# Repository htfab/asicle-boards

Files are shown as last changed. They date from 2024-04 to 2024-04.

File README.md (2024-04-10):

# Asicle boards

Contains two PCB designs for the Wordle clone on ASIC, [Asicle](https://github.com/htfab/asicle).

Asicle DIY uses only discrete transistors and passives for the supporting circuitry, with through-hole components for everything except the ASIC.

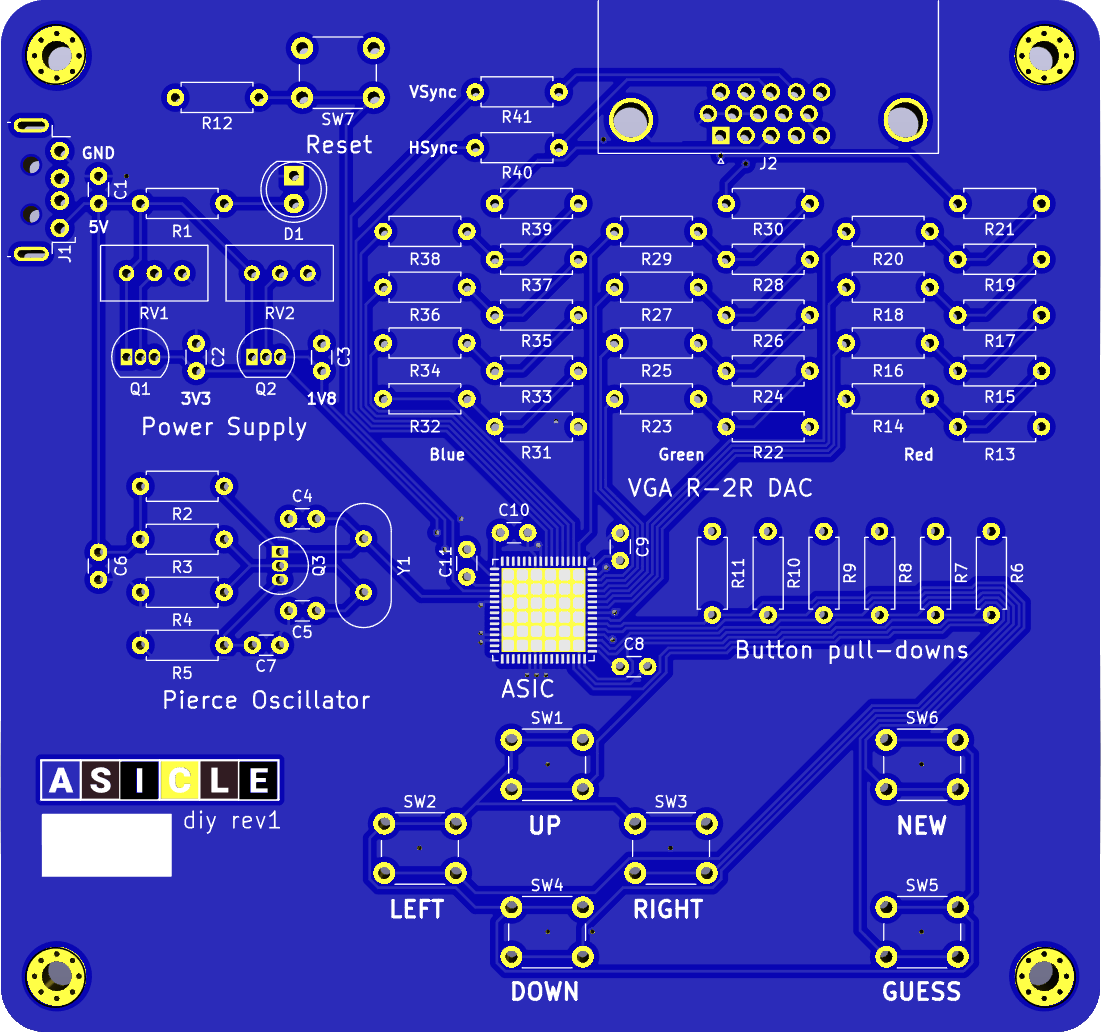
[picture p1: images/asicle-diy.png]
Asicle DIY front render


Asicle PRO uses standard commercial chips for voltage regulation, clock generation and VGA buffering for better reliability, and is designed with surface-mount components.

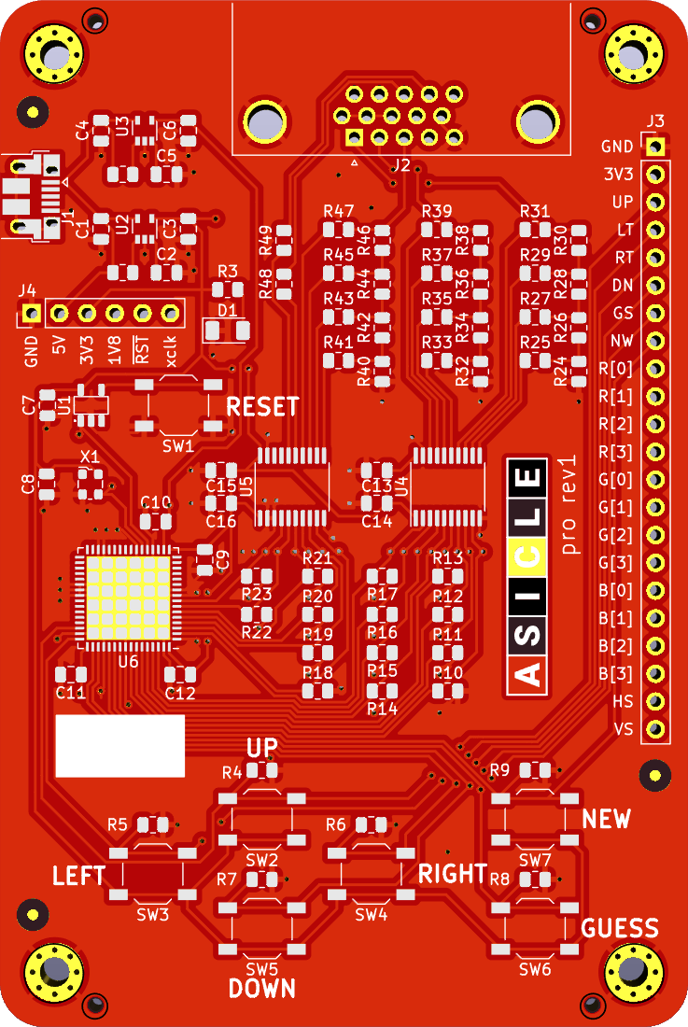
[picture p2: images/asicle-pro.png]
Asicle PRO front render


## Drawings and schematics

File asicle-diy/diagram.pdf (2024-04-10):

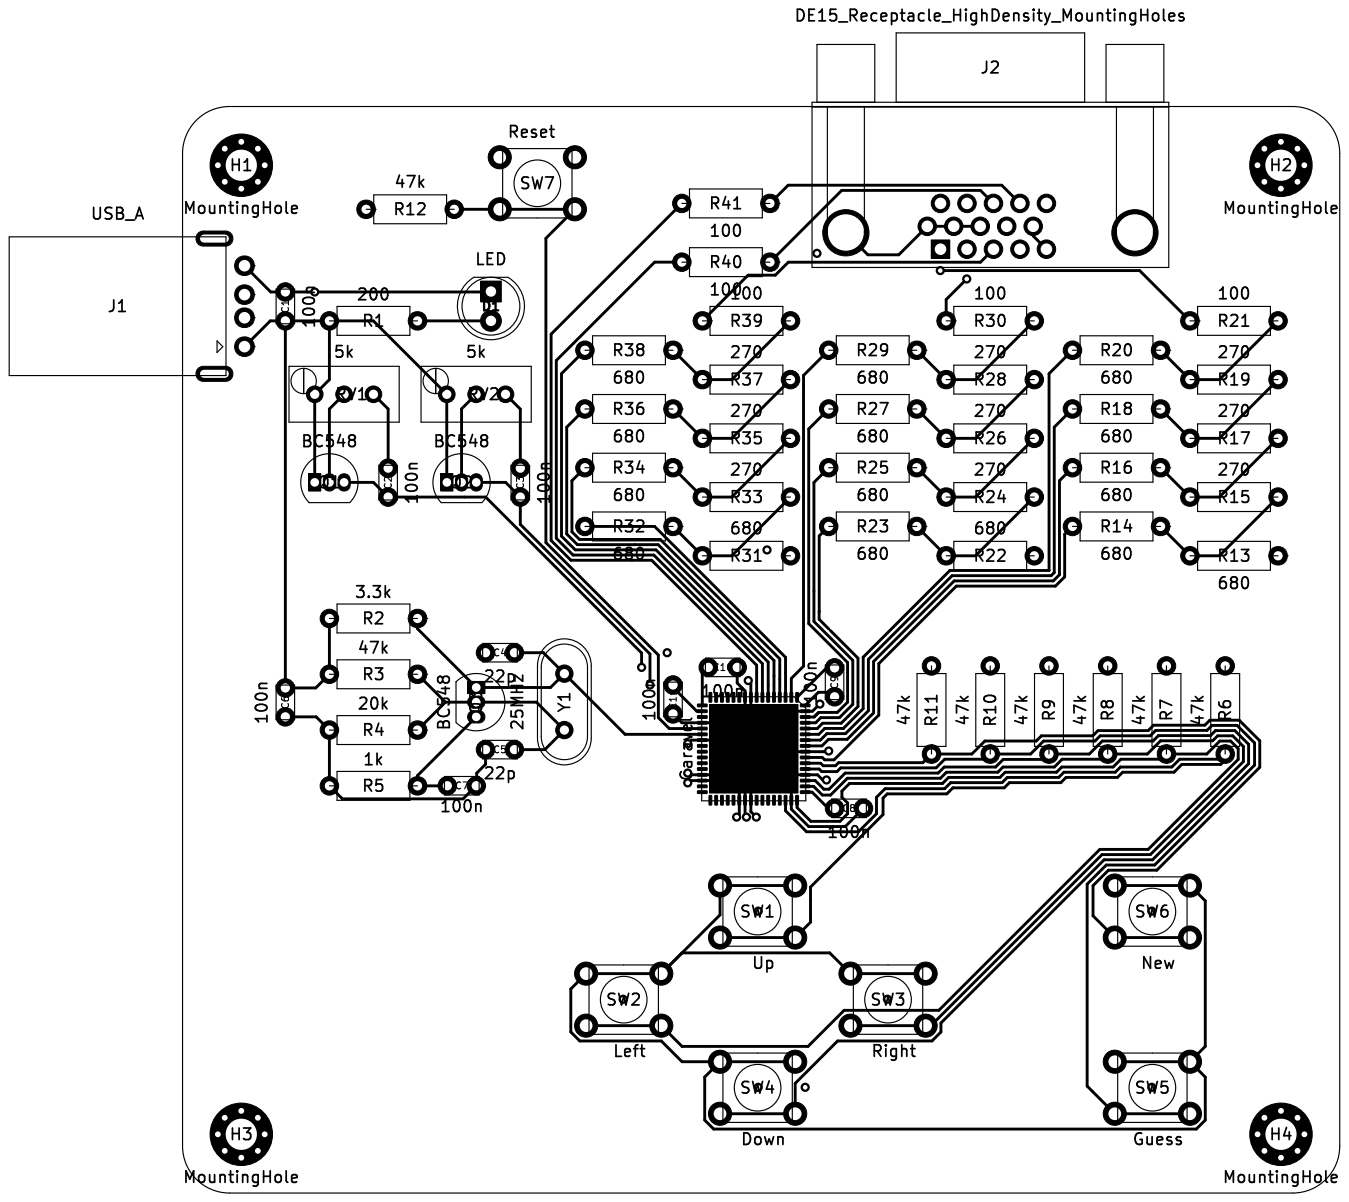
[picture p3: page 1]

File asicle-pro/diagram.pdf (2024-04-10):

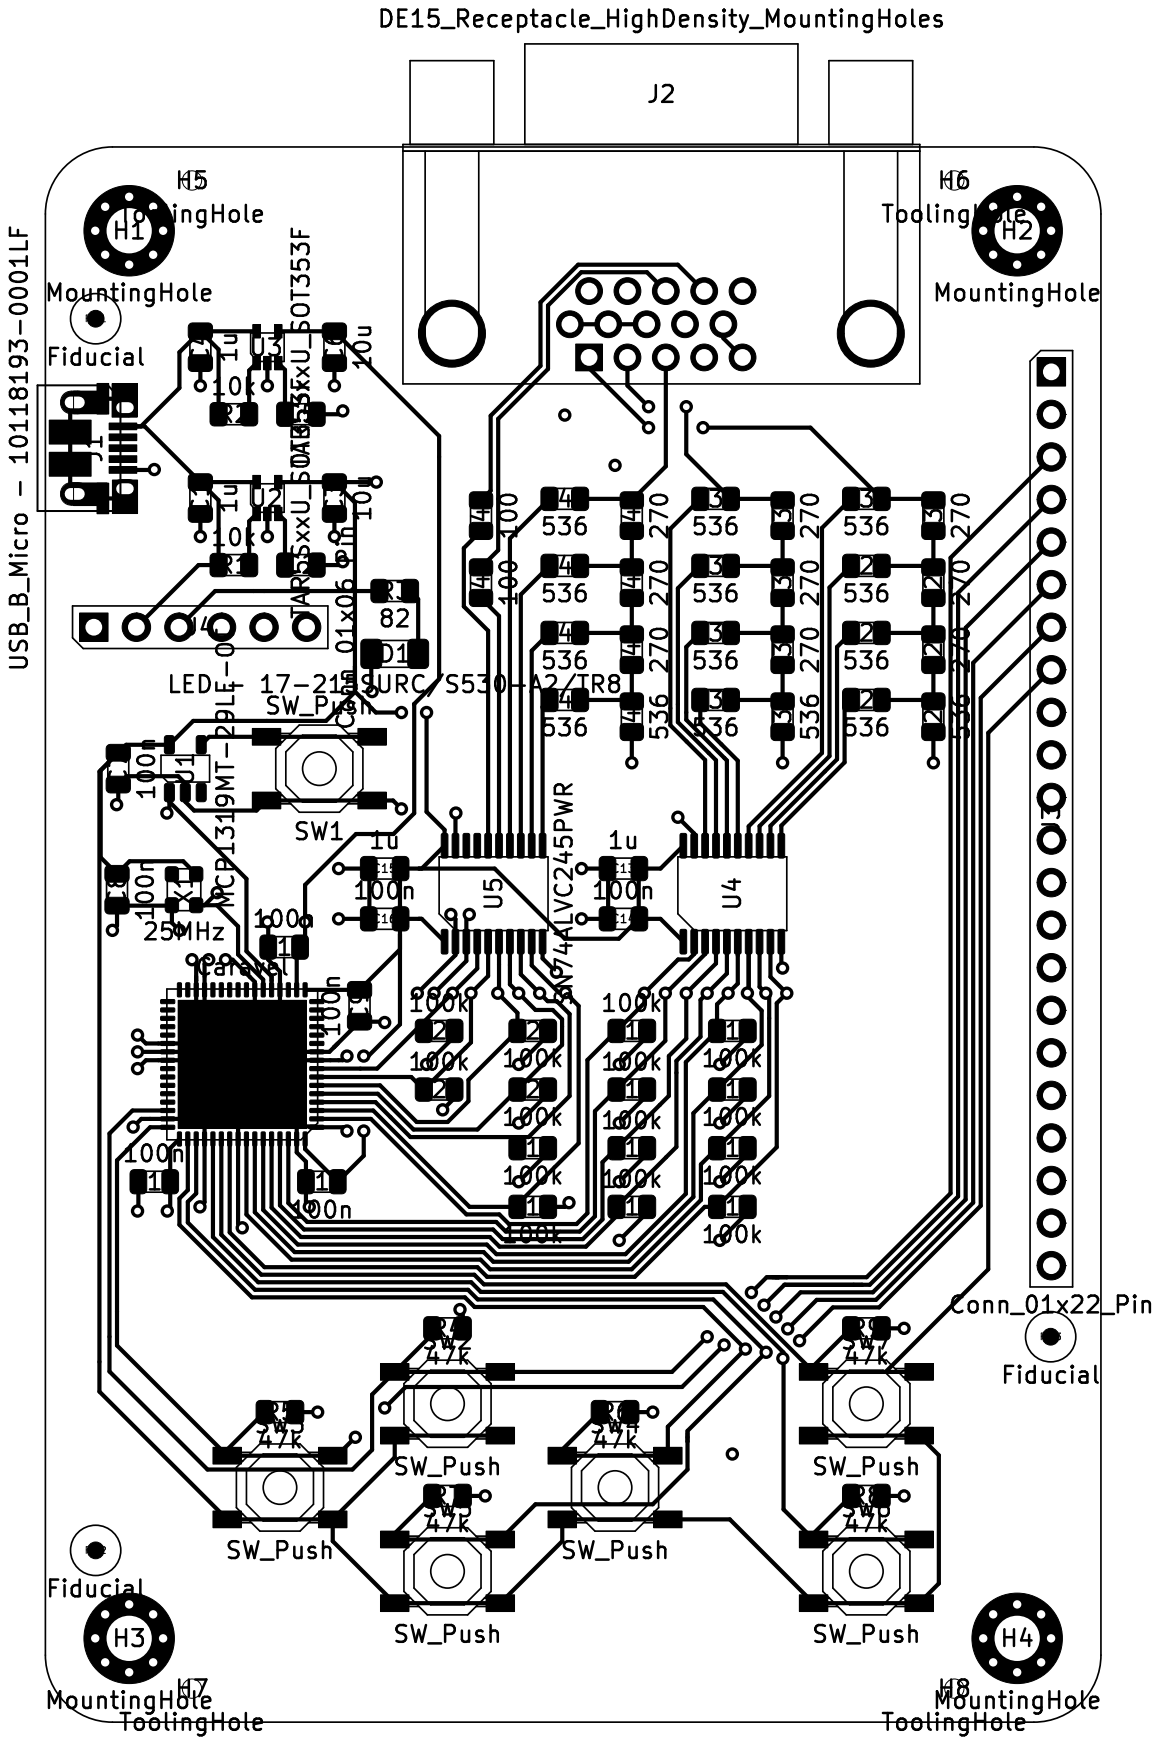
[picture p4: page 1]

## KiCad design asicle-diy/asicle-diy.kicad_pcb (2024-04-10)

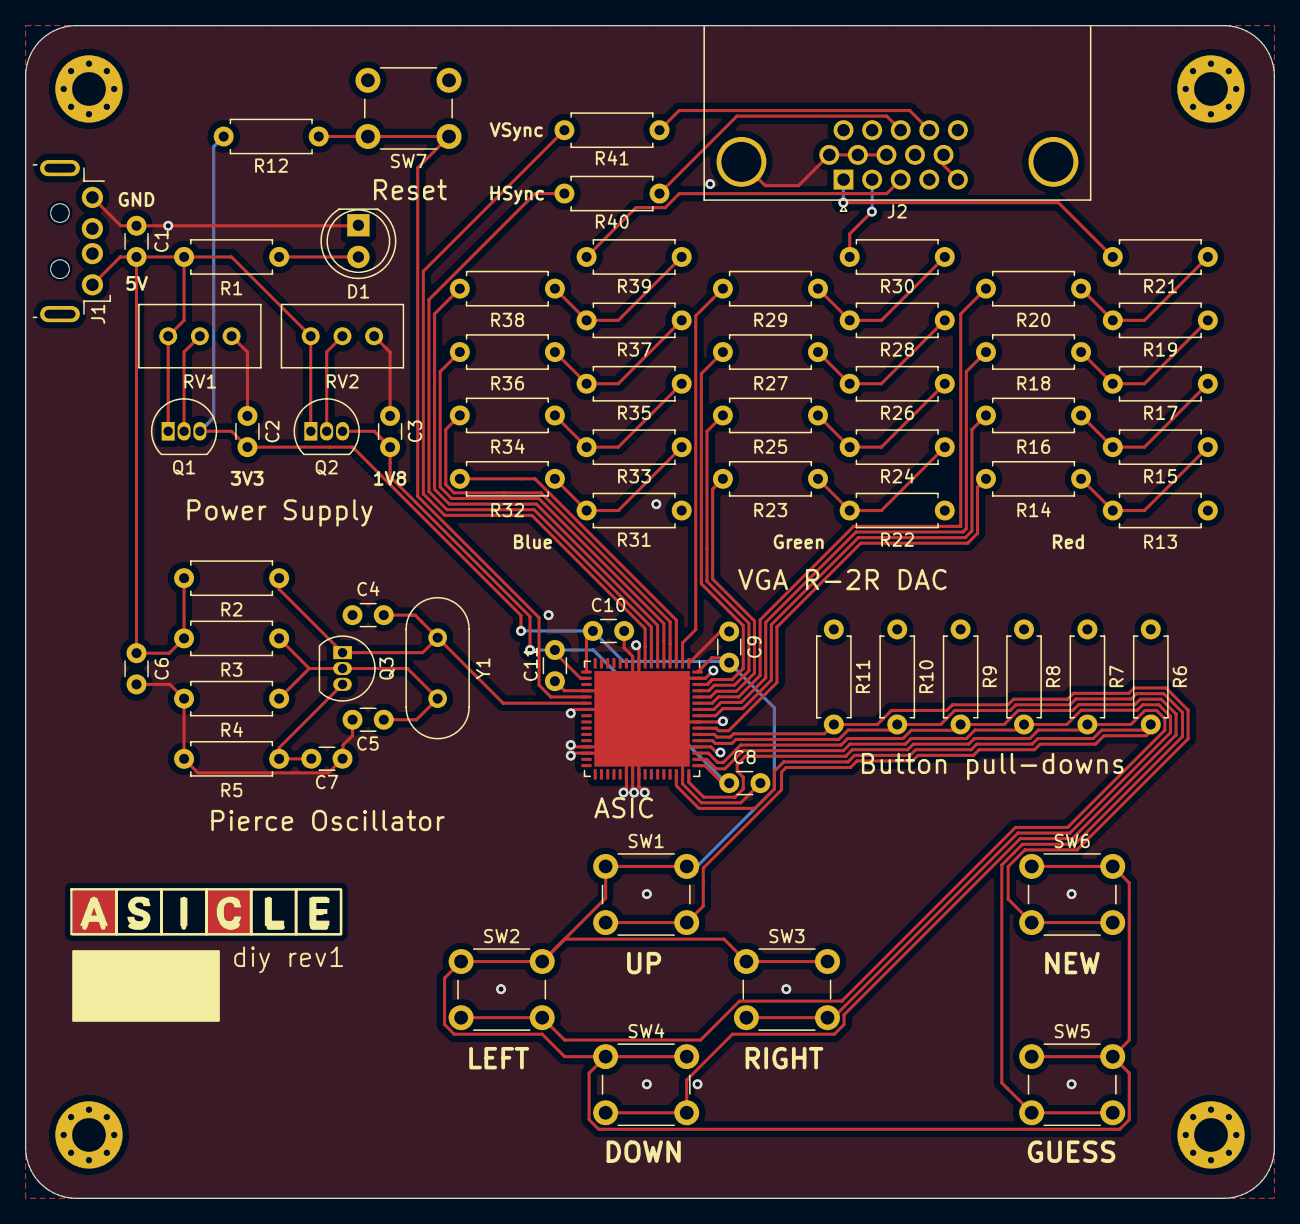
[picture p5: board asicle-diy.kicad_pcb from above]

Board: 2 copper layers, 100.1 x 94.0 mm, 73 parts (0 on the bottom side), 48 nets.

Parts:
C1, C2, C3, C6, C7, C8, C9, C10, C11: 100n; C_Disc_D3.0mm_W1.6mm_P2.50mm
C4, C5: 22p; C_Disc_D3.0mm_W1.6mm_P2.50mm
D1: LED; LED_D5.0mm
H1, H2, H3, H4: MountingHole; MountingHole_2.7mm_M2.5_Pad_Via
J1: USB_A; USB_A_LC_THT
J2: DE15_Receptacle_HighDensity_MountingHoles; DSUB-15-HD_Female_Horizontal_P2.29x1.98mm_EdgePinOffset8.35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
Q1, Q2, Q3: BC548; TO-92_Inline
R1: 200; R_Axial_DIN0207_L6.3mm_D2.5mm_P7.62mm_Horizontal
R2: 3.3k; R_Axial_DIN0207_L6.3mm_D2.5mm_P7.62mm_Horizontal
R3, R6, R7, R8, R9, R10, R11, R12: 47k; R_Axial_DIN0207_L6.3mm_D2.5mm_P7.62mm_Horizontal
R4: 20k; R_Axial_DIN0207_L6.3mm_D2.5mm_P7.62mm_Horizontal
R5: 1k; R_Axial_DIN0207_L6.3mm_D2.5mm_P7.62mm_Horizontal
R13, R14, R16, R18, R20, R22, R23, R25, R27, R29, R31, R32, R34, R36, R38: 680; R_Axial_DIN0207_L6.3mm_D2.5mm_P7.62mm_Horizontal
R15, R17, R19, R24, R26, R28, R33, R35, R37: 270; R_Axial_DIN0207_L6.3mm_D2.5mm_P7.62mm_Horizontal
R21, R30, R39, R40, R41: 100; R_Axial_DIN0207_L6.3mm_D2.5mm_P7.62mm_Horizontal
RV1, RV2: 5k; Potentiometer_Bourns_3296W_Vertical
SW1: Up; SW_PUSH_6mm
SW2: Left; SW_PUSH_6mm
SW3: Right; SW_PUSH_6mm
SW4: Down; SW_PUSH_6mm
SW5: Guess; SW_PUSH_6mm
SW6: New; SW_PUSH_6mm
SW7: Reset; SW_PUSH_6mm
U3: Caravel; QFN-64-1EP_9x9mm_P0.5mm_EP7.65x7.65mm
Y1: 25MHz; Crystal_HC49-U_Vertical

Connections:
+1V8: C3.1, C8.1, C11.1, Q2.3 (E), U3.18 (vccd), U3.49 (vccd1)
+3V3: C2.1, C9.2, C10.1, Q1.3 (E), R12.2, SW1.1, SW2.1, SW3.1, SW4.1, SW5.1, SW6.1, U3.17 (vddio), U3.64 (vddio)
+5V: C1.1, C6.1, J1.1 (VBUS), Q1.1 (C), Q2.1 (C), R1.1, R2.1, R3.1, RV1.1, RV2.1
CLK: C4.2, Q3.1 (C), R2.2, U3.22 (clock), Y1.2
GND: C1.2, C2.2, C3.2, C4.1, C5.1, C6.2, C7.1, C8.2, C9.1, C10.2, C11.2, D1.1 (K), H1.1, H2.1, H3.1, H4.1, J1.4 (GND), J1.5 (Shield), J2.0, J2.5, J2.6, J2.7, J2.8, J2.10, R4.1, R5.1, R6.1, R7.1, R8.1, R9.1, R10.1, R11.1, R13.2, R22.1, R31.1, RV1.3, RV2.3, SW7.2, U3.1 (vssa2), U3.9 (vdda2), U3.10 (vssd2), U3.20 (vssa), U3.23 (vssd), U3.29 (vssio), U3.30 (vdda), U3.38 (vssa1), U3.39 (vssd1), U3.40 (vdda1), U3.47 (vdda1), U3.52 (vssa1), U3.56 (vssio), U3.63 (vccd2), U3.65 (ThermalPad)
IN_DOWN: R9.2, SW4.2, U3.51 (mprj_io[15])
IN_GUESS: R10.2, SW5.2, U3.53 (mprj_io[16])
IN_LEFT: R7.2, SW2.2, U3.48 (mprj_io[13])
IN_NEW: R11.2, SW6.2, U3.54 (mprj_io[17])
IN_RIGHT: R8.2, SW3.2, U3.50 (mprj_io[14])
IN_UP: R6.2, SW1.2, U3.46 (mprj_io[12])
unnamed: D1.2 (A), R1.2
unnamed: Q1.2 (B), RV1.2
unnamed: Q2.2 (B), RV2.2
unnamed: C5.2, Q3.2 (B), R3.2, R4.2, Y1.1
unnamed: C7.2, Q3.3 (E), R5.2
unnamed: R13.1, R14.2, R15.1
unnamed: R15.2, R16.2, R17.1
unnamed: R17.2, R18.2, R19.1
unnamed: R19.2, R20.2, R21.1
unnamed: R22.2, R23.2, R24.1
unnamed: R24.2, R25.2, R26.1
unnamed: R26.2, R27.2, R28.1
unnamed: R28.2, R29.2, R30.1
unnamed: R31.2, R32.2, R33.1
unnamed: R33.2, R34.2, R35.1
unnamed: R35.2, R36.2, R37.1
unnamed: R37.2, R38.2, R39.1
OUT_B0: R32.1, U3.3 (mprj_io[26])
OUT_B1: R34.1, U3.4 (mprj_io[27])
OUT_B2: R36.1, U3.5 (mprj_io[28])
OUT_B3: R38.1, U3.6 (mprj_io[29])
OUT_G0: R23.1, U3.60 (mprj_io[22])
OUT_G1: R25.1, U3.61 (mprj_io[23])
OUT_G2: R27.1, U3.62 (mprj_io[24])
OUT_G3: R29.1, U3.2 (mprj_io[25])
OUT_HS: R40.1, U3.7 (mprj_io[30])
OUT_R0: R14.1, U3.55 (mprj_io[18])
OUT_R1: R16.1, U3.57 (mprj_io[19])
OUT_R2: R18.1, U3.58 (mprj_io[20])
OUT_R3: R20.1, U3.59 (mprj_io[21])
OUT_VS: R41.1, U3.8 (mprj_io[31])
VGA_BLUE: J2.3, R39.2
VGA_GREEN: J2.2, R30.2
VGA_HSYNC: J2.13, R40.2
VGA_RED: J2.1, R21.2
VGA_VSYNC: J2.14, R41.2
~RST: R12.1, SW7.1, U3.21 (resetb)

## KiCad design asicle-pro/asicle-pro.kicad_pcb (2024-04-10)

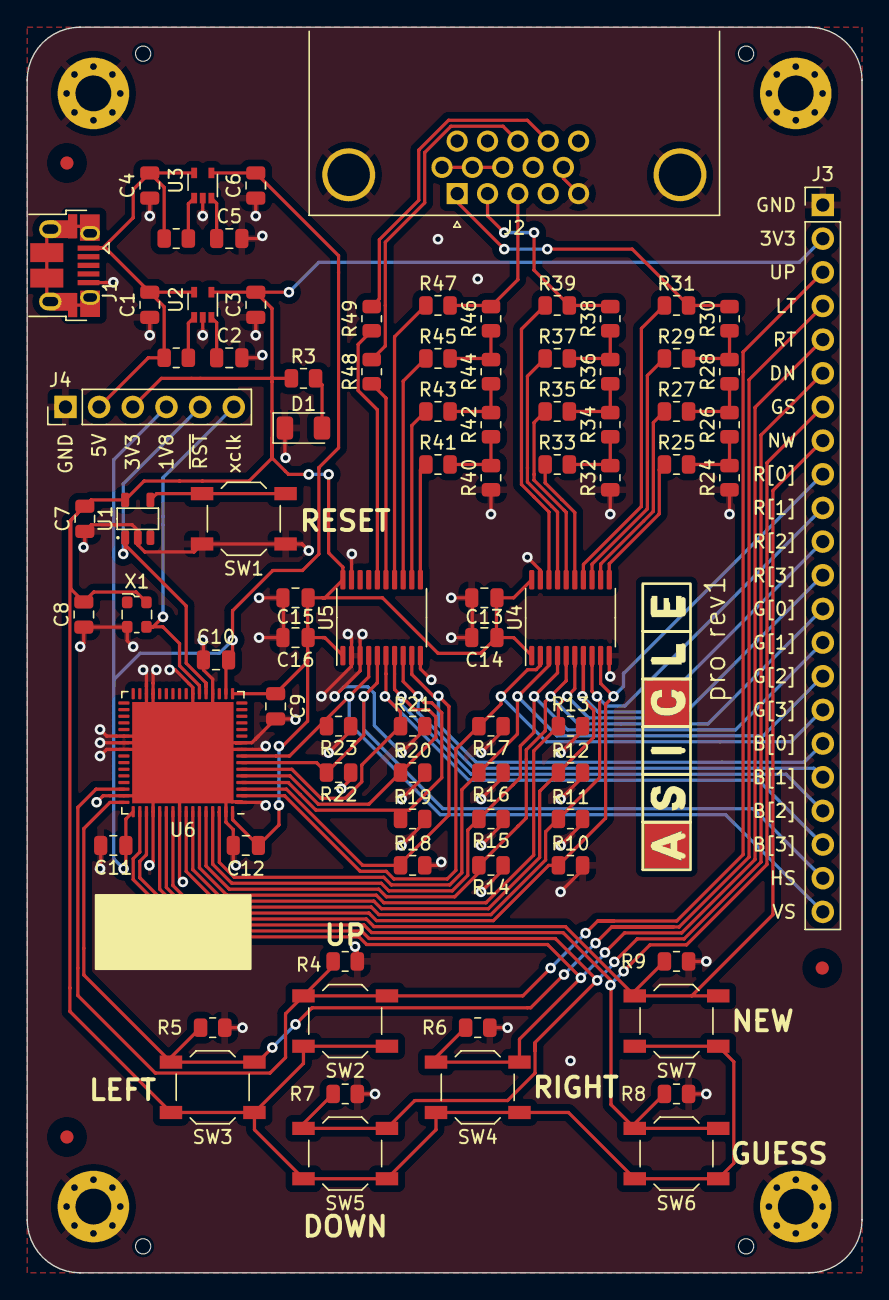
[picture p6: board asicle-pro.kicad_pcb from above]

Board: 2 copper layers, 63.0 x 94.0 mm, 95 parts (0 on the bottom side), 60 nets.

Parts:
C1, C4, C13, C15: 1u; C_0805_2012Metric
C2, C5: 10n; C_0805_2012Metric
C3, C6: 10u; C_0805_2012Metric
C7, C8, C9, C10, C11, C12, C14, C16: 100n; C_0805_2012Metric
D1: LED - 17-215SURC/S530-A2/TR8; LED_1206_3216Metric
FID1, FID2, FID3: Fiducial; Fiducial_1mm_Mask3mm
H1, H2, H3, H4: MountingHole; MountingHole_2.7mm_M2.5_Pad_Via
H5, H6, H7, H8: ToolingHole; ToolingHole-JLCSMT
J1: USB_B_Micro - 10118193-0001LF; USB_Micro-B_Amphenol_10103594-0001LF_Horizontal
J2: DE15_Receptacle_HighDensity_MountingHoles; DSUB-15-HD_Female_Horizontal_P2.29x1.98mm_EdgePinOffset8.35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
J3: Conn_01x22_Pin; PinHeader_1x22_P2.54mm_Vertical
J4: Conn_01x06_Pin; PinHeader_1x06_P2.54mm_Vertical
R1, R2: 10k; R_0805_2012Metric
R3: 82; R_0805_2012Metric
R4, R5, R6, R7, R8, R9: 47k; R_0805_2012Metric
R10, R11, R12, R13, R14, R15, R16, R17, R18, R19, R20, R21, R22, R23: 100k; R_0805_2012Metric
R24, R25, R27, R29, R31, R32, R33, R35, R37, R39, R40, R41, R43, R45, R47: 536; R_0805_2012Metric
R26, R28, R30, R34, R36, R38, R42, R44, R46: 270; R_0805_2012Metric
R48, R49: 100; R_0805_2012Metric
SW1, SW2, SW3, SW4, SW5, SW6, SW7: SW_Push; SW_SPST_TL3342
U1: MCP1319MT-29LE-OT; PoR_5_SOT23
U2, U3: TAR5SxxU_SOT353F; SOT-353F
U4, U5: SN74ALVC245PWR; TSSOP-20_4.4x6.5mm_P0.65mm
U6: Caravel; QFN-64-1EP_9x9mm_P0.5mm_EP7.65x7.65mm
X1: 25MHz; Oscillator_SMD_ECS_2520MV-xxx-xx-4Pin_2.5x2.0mm

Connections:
+1V8: C6.2, C10.1, C11.1, J4.4, U3.4 (VOUT), U6.18 (vccd), U6.49 (vccd1)
+3V3: C3.2, C7.2, C8.2, C9.1, C12.2, C13.1, C14.1, C15.1, C16.1, J3.2, J4.3, R3.1, SW2.2, SW3.2, SW4.2, SW5.2, SW6.2, SW7.2, U1.5 (VDD), U2.4 (VOUT), U4.1 (DIR), U4.20 (VCC), U5.1 (DIR), U5.20 (VCC), U6.17 (vddio), U6.64 (vddio), X1.4 (V+)
+5V: C1.2, C4.2, J1.1 (VBUS), J4.2, R1.2, R2.2, U2.5 (VIN), U3.5 (VIN)
GND: C1.1, C2.2, C3.1, C4.1, C5.2, C6.1, C7.1, C8.1, C9.2, C10.2, C11.2, C12.1, C13.2, C14.2, C15.2, C16.2, D1.1 (K), H1.1, H2.1, H3.1, H4.1, J1.5 (GND), J2.0, J2.5, J2.6, J2.7, J2.8, J2.10, J3.1, J4.1, R4.2, R5.2, R6.2, R7.2, R8.2, R9.2, R10.2, R11.2, R12.2, R13.2, R14.1, R15.1, R16.1, R17.1, R18.2, R19.2, R20.2, R21.2, R22.1, R23.1, R24.1, R32.1, R40.1, SW1.1, U1.2 (VSS), U2.2 (GND), U3.2 (GND), U4.10 (GND), U4.19 (~OE), U5.2 (A1), U5.3 (A2), U5.10 (GND), U5.19 (~OE), U6.1 (vssa2), U6.9 (vdda2), U6.10 (vssd2), U6.20 (vssa), U6.23 (vssd), U6.29 (vssio), U6.30 (vdda), U6.38 (vssa1), U6.39 (vssd1), U6.40 (vdda1), U6.47 (vdda1), U6.52 (vssa1), U6.56 (vssio), U6.63 (vccd2), U6.65 (ThermalPad), X1.2 (GND)
IN_DOWN: J3.6, R7.1, SW5.1, U6.51 (mprj_io[15])
IN_GUESS: J3.7, R8.1, SW6.1, U6.53 (mprj_io[16])
IN_LEFT: J3.4, R5.1, SW3.1, U6.48 (mprj_io[13])
IN_NEW: J3.8, R9.1, SW7.1, U6.54 (mprj_io[17])
IN_RIGHT: J3.5, R6.1, SW4.1, U6.50 (mprj_io[14])
IN_UP: J3.3, R4.1, SW2.1, U6.46 (mprj_io[12])
unnamed: D1.2 (A), R3.2
unnamed: R24.2, R25.2, R26.1
unnamed: R26.2, R27.2, R28.1
unnamed: R28.2, R29.2, R30.1
unnamed: R32.2, R33.2, R34.1
unnamed: R34.2, R35.2, R36.1
unnamed: R36.2, R37.2, R38.1
unnamed: R40.2, R41.2, R42.1
unnamed: R42.2, R43.2, R44.1
unnamed: R44.2, R45.2, R46.1
unnamed: SW1.2, U1.4 (~MR)
unnamed: R1.1, U2.1 (Control)
unnamed: C2.1, U2.3 (Noise)
unnamed: R2.1, U3.1 (Control)
unnamed: C5.1, U3.3 (Noise)
OUT_B0: J3.17, R18.1, U5.9 (A8), U6.3 (mprj_io[26])
OUT_B1: J3.18, R19.1, U5.8 (A7), U6.4 (mprj_io[27])
OUT_B2: J3.19, R20.1, U5.7 (A6), U6.5 (mprj_io[28])
OUT_B3: J3.20, R21.1, U5.6 (A5), U6.6 (mprj_io[29])
OUT_G0: J3.13, R14.2, U4.5 (A4), U6.60 (mprj_io[22])
OUT_G1: J3.14, R15.2, U4.4 (A3), U6.61 (mprj_io[23])
OUT_G2: J3.15, R16.2, U4.3 (A2), U6.62 (mprj_io[24])
OUT_G3: J3.16, R17.2, U4.2 (A1), U6.2 (mprj_io[25])
OUT_HS: J3.21, R22.2, U5.5 (A4), U6.7 (mprj_io[30])
OUT_R0: J3.9, R10.1, U4.9 (A8), U6.55 (mprj_io[18])
OUT_R1: J3.10, R11.1, U4.8 (A7), U6.57 (mprj_io[19])
OUT_R2: J3.11, R12.1, U4.7 (A6), U6.58 (mprj_io[20])
OUT_R3: J3.12, R13.1, U4.6 (A5), U6.59 (mprj_io[21])
OUT_VS: J3.22, R23.2, U5.4 (A3), U6.8 (mprj_io[31])
VGA_B0: R41.1, U5.11 (B8)
VGA_B1: R43.1, U5.12 (B7)
VGA_B2: R45.1, U5.13 (B6)
VGA_B3: R47.1, U5.14 (B5)
VGA_BLUE: J2.3, R46.2, R47.2
VGA_G0: R33.1, U4.15 (B4)
VGA_G1: R35.1, U4.16 (B3)
VGA_G2: R37.1, U4.17 (B2)
VGA_G3: R39.1, U4.18 (B1)
VGA_GREEN: J2.2, R38.2, R39.2
VGA_HS: R48.1, U5.15 (B4)
VGA_HSYNC: J2.13, R48.2
VGA_R0: R25.1, U4.11 (B8)
VGA_R1: R27.1, U4.12 (B7)
VGA_R2: R29.1, U4.13 (B6)
VGA_R3: R31.1, U4.14 (B5)
VGA_RED: J2.1, R30.2, R31.2
VGA_VS: R49.1, U5.16 (B3)
VGA_VSYNC: J2.14, R49.2
xclk: J4.6, U6.22 (clock), X1.3 (OUT)
~RST: J4.5, U1.1 (~RST), U6.21 (resetb)
